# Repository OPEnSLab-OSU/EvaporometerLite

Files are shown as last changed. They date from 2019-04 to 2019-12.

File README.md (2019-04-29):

# EvaporometerLite
This repository contains all the files needed to recreate the Evaporometer LITE.
# How to Setup
Follow assembly guide located in the documentation folder. 

# Directory Layout
Documentation contains assembly procedure, BOM.

CAD contains .stl and .step files of 3D printed components. 

PCB contains PCB design.

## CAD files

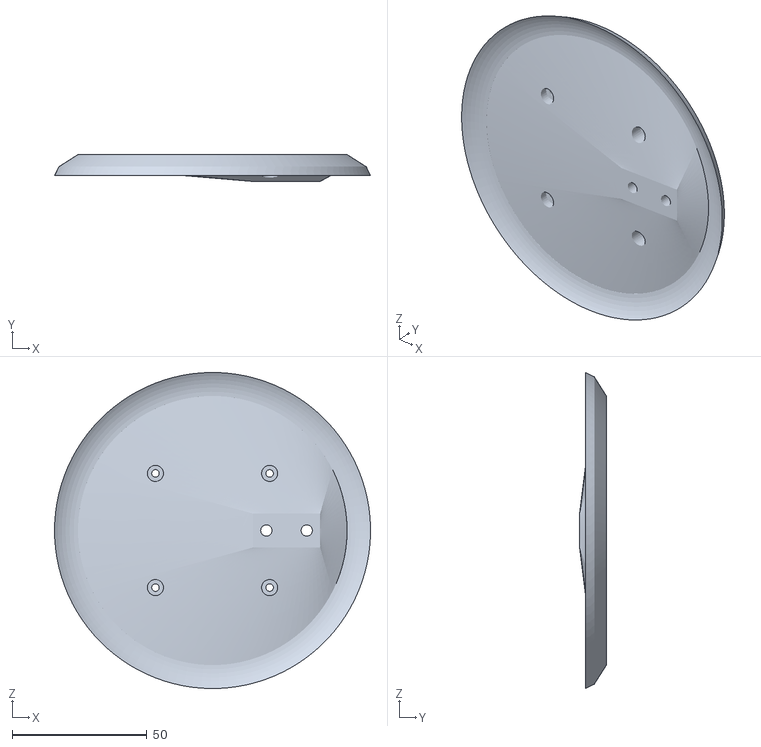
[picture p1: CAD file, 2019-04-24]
CAD /Coupler.stl
117.4 x 10.0 x 117.4

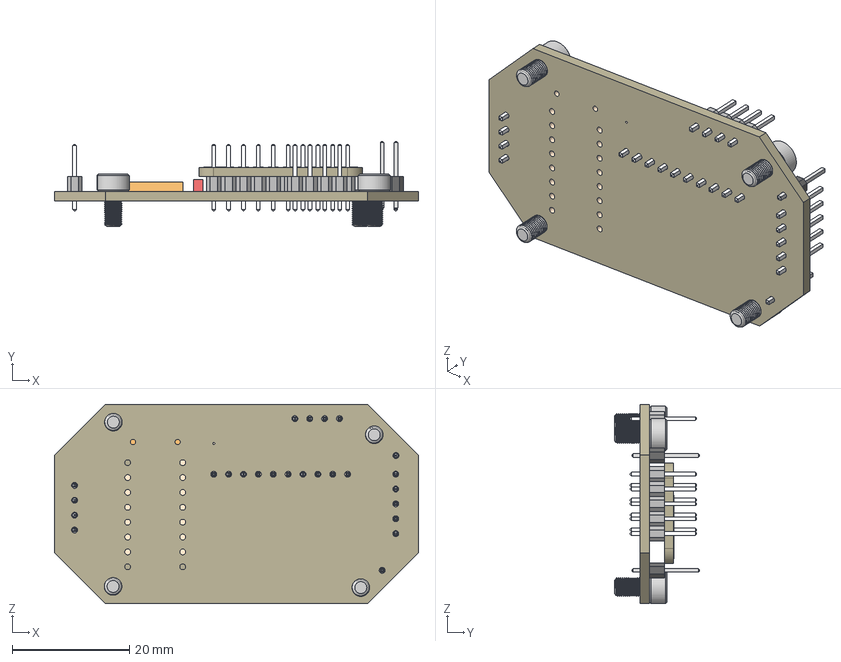
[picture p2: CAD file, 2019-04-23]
PCB/PCB Board.step
62.2 x 14.5 x 34.1 mm
Board
ADS1115IDGST
1µF x 8
MOUNTINGHOLE2.5 x 2
FIDUCIAL"" x 2
ADAFRUIT_TEXT_20MM
ADAFRUIT_2.5MM
Board_1
1X04 x 2
1X05
1X10
1X01 x 2
SJ
90751A110 x 4

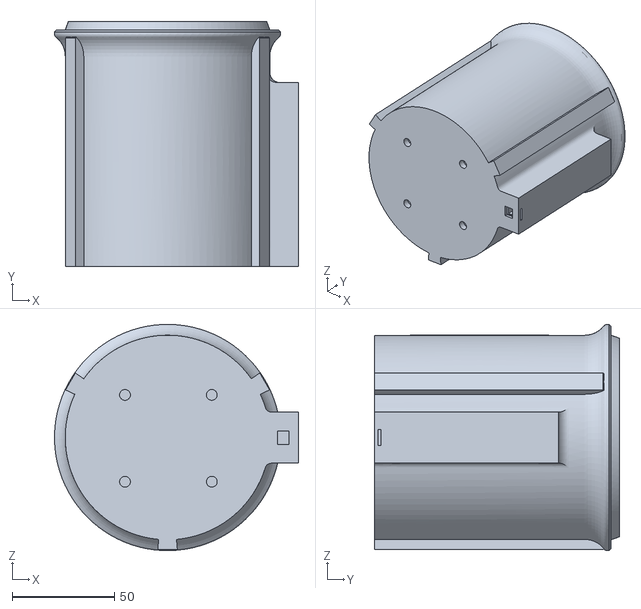
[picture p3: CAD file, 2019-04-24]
CAD /Evaporimter.stl
119.3 x 119.9 x 110.6

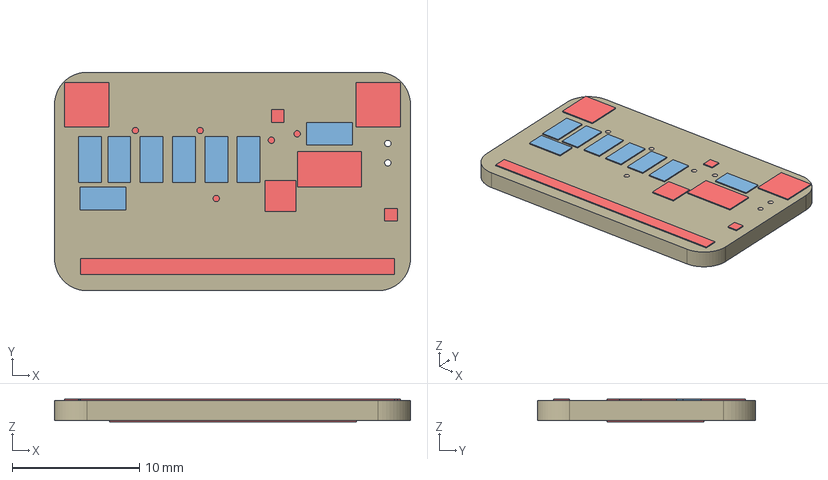
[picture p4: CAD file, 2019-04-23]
PCB/Adafruit ADS1115 16Bit I2C ADC.step
27.9 x 17.1 x 1.77 mm
Board
ADS1115IDGST
1µF x 8
1X10_ROUND70
MOUNTINGHOLE2.5 x 2
FIDUCIAL"" x 2
ADAFRUIT_TEXT_20MM
ADAFRUIT_2.5MM

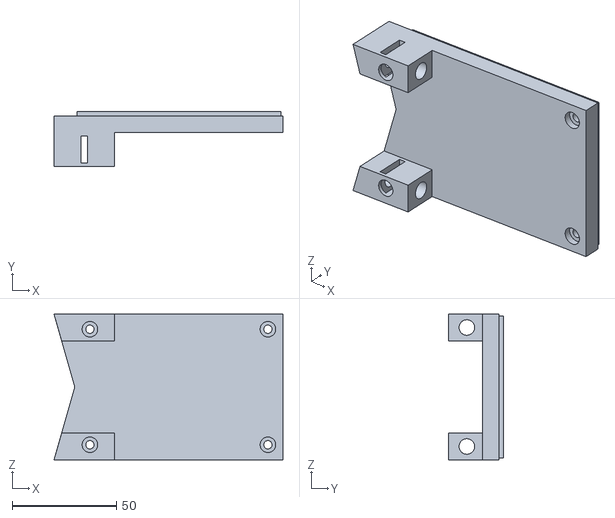
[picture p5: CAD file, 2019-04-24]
CAD /Bottom Enclosure.stl
110.0 x 26.2 x 70.0

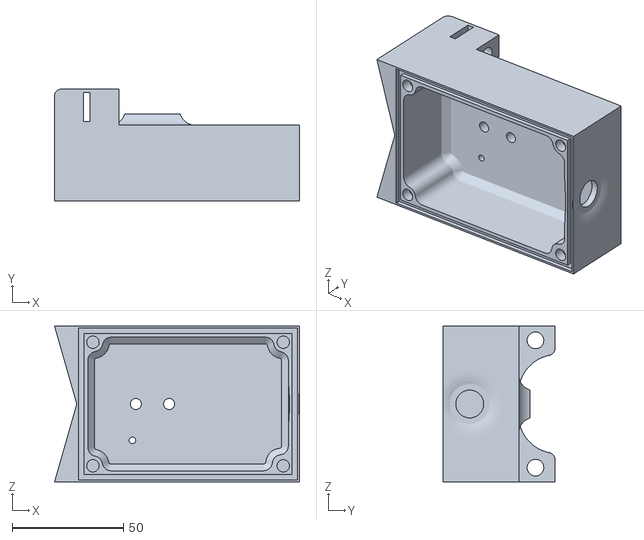
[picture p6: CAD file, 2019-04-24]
CAD /Top Enclosure.stl
110.0 x 50.2 x 70.0

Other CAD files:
CAD /Container Evaporometer LITE.step
CAD /Bottom Enclosure Evaporimeter LITE.step
CAD /Top Enclosure Evaporimeter LITE.step
CAD /Coupler Evaporimeter LITE.step

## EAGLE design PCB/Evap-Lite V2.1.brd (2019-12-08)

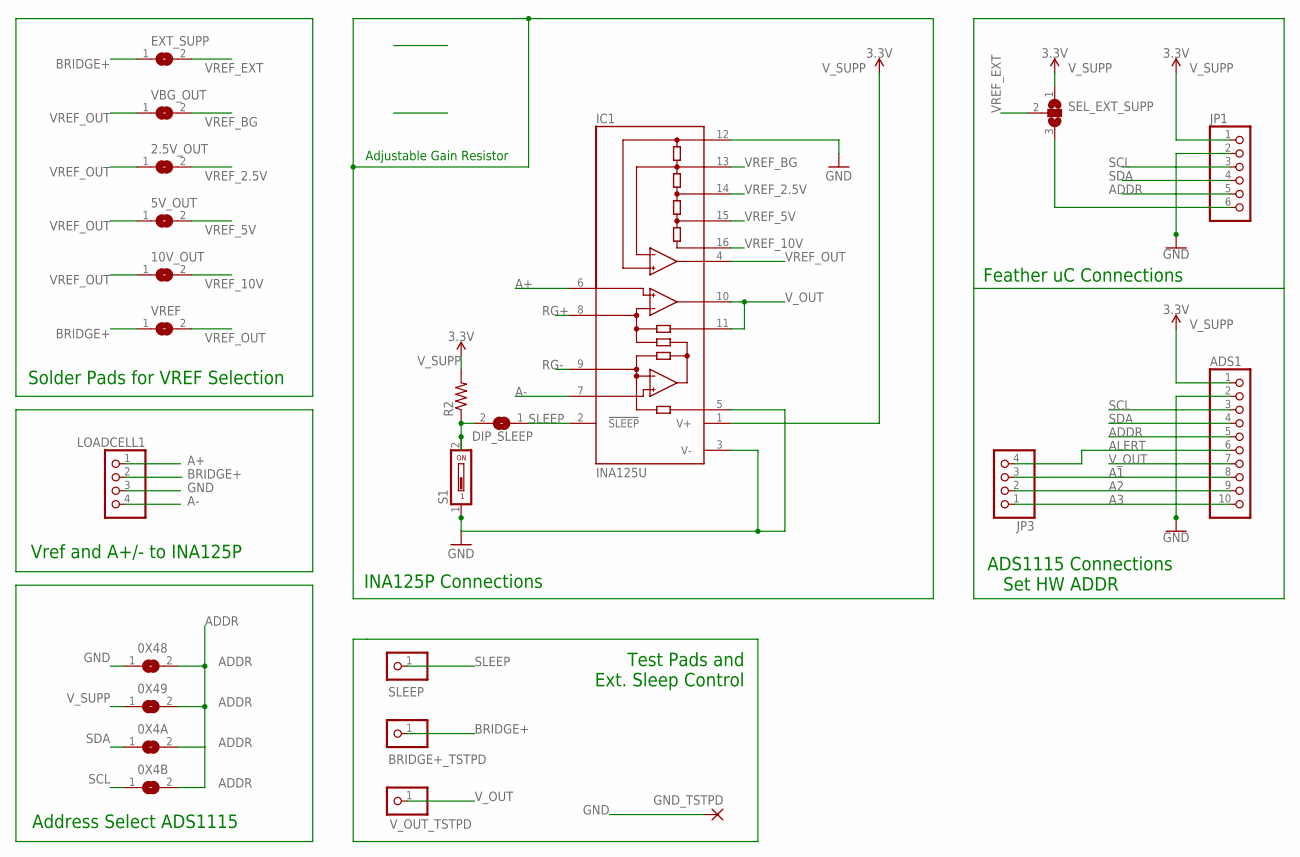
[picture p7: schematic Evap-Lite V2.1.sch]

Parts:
0X4A, 0X4B, 0X48, 0X49, 2.5V_OUT, 5V_OUT, 10V_OUT: SJ
ADS1: PINHD-1X10; 1X10
BRIDGE+_TSTPD: PINHD-1X1; 1X01
DIP_SLEEP: SJ
EXT_SUPP: SJ
GND_TSTPD: WIREPADSMD2,54-5,08; SMD2,54-5,08
IC1: INA125U; SO16-1
JP1: PINHD-1X6; 1X06
JP3: PINHD-1X4; 1X04
LOADCELL1: PINHD-1X4; 1X04
R2: R-US_R1206; R1206
S1: DS01; DS-01
SEL_EXT_SUPP: SJ2WW; SJ_2W
SLEEP: PINHD-1X1; 1X01
VBG_OUT: SJ
VREF: SJ
V_OUT_TSTPD: PINHD-1X1; 1X01

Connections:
A1: ADS1.8, JP3.3
A2: ADS1.9, JP3.2
A3: ADS1.10, JP3.1
A+: IC1.6 (+IN), LOADCELL1.1
A-: IC1.7 (-IN), LOADCELL1.4
ADDR: 0X4A.2, 0X4B.2, 0X48.2, 0X49.2, ADS1.5, JP1.5
ALERT: ADS1.6, JP3.4
BRIDGE+: BRIDGE+_TSTPD.1, EXT_SUPP.1, LOADCELL1.2, VREF.1
GND: 0X48.1, ADS1.2, GND_TSTPD.1, IC1.3 (V-), IC1.5 (REF), IC1.12 (REFCOM), JP1.2, LOADCELL1.3, S1.1
unnamed: JP1.6, SEL_EXT_SUPP.3
unnamed: DIP_SLEEP.2, R2.1, S1.2
RG+: IC1.8 (RG)
RG-: IC1.9 (RG)
SCL: 0X4B.1, ADS1.3, JP1.3
SDA: 0X4A.1, ADS1.4, JP1.4
SLEEP: DIP_SLEEP.1, IC1.2 (!SLEEP), SLEEP.1
VREF_2.5V: 2.5V_OUT.2, IC1.14 (REF2.5)
VREF_5V: 5V_OUT.2, IC1.15 (REF5)
VREF_10V: 10V_OUT.2, IC1.16 (REF10)
VREF_BG: IC1.13 (REFBG), VBG_OUT.2
VREF_EXT: EXT_SUPP.2, SEL_EXT_SUPP.2
VREF_OUT: 2.5V_OUT.1, 5V_OUT.1, 10V_OUT.1, IC1.4 (REFOUT), VBG_OUT.1, VREF.2
V_OUT: ADS1.7, IC1.10 (OUT), IC1.11 (SENSE), V_OUT_TSTPD.1
V_SUPP: 0X49.1, ADS1.1, IC1.1 (V+), JP1.1, R2.2, SEL_EXT_SUPP.1

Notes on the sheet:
Vref and A+/- to INA125P
Solder Pads for VREF Selection
Feather uC Connections
Address Select ADS1115
ADS1115 Connections Set HW ADDR
Adjustable Gain Resistor
INA125P Connections
Test Pads and Ext. Sleep Control

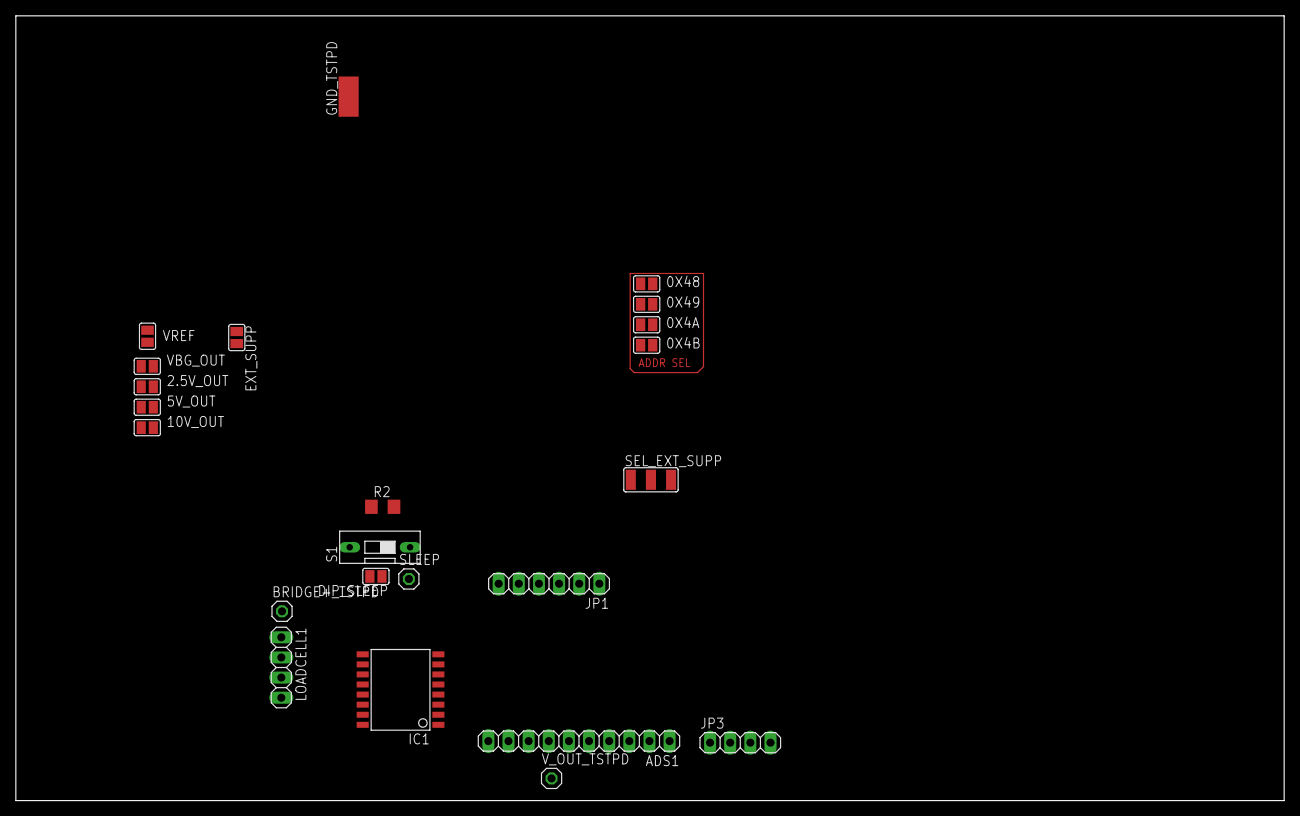
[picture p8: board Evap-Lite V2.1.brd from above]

Board: 2 copper layers, 160.0 x 99.0 mm, 23 parts (0 on the bottom side), 22 nets.

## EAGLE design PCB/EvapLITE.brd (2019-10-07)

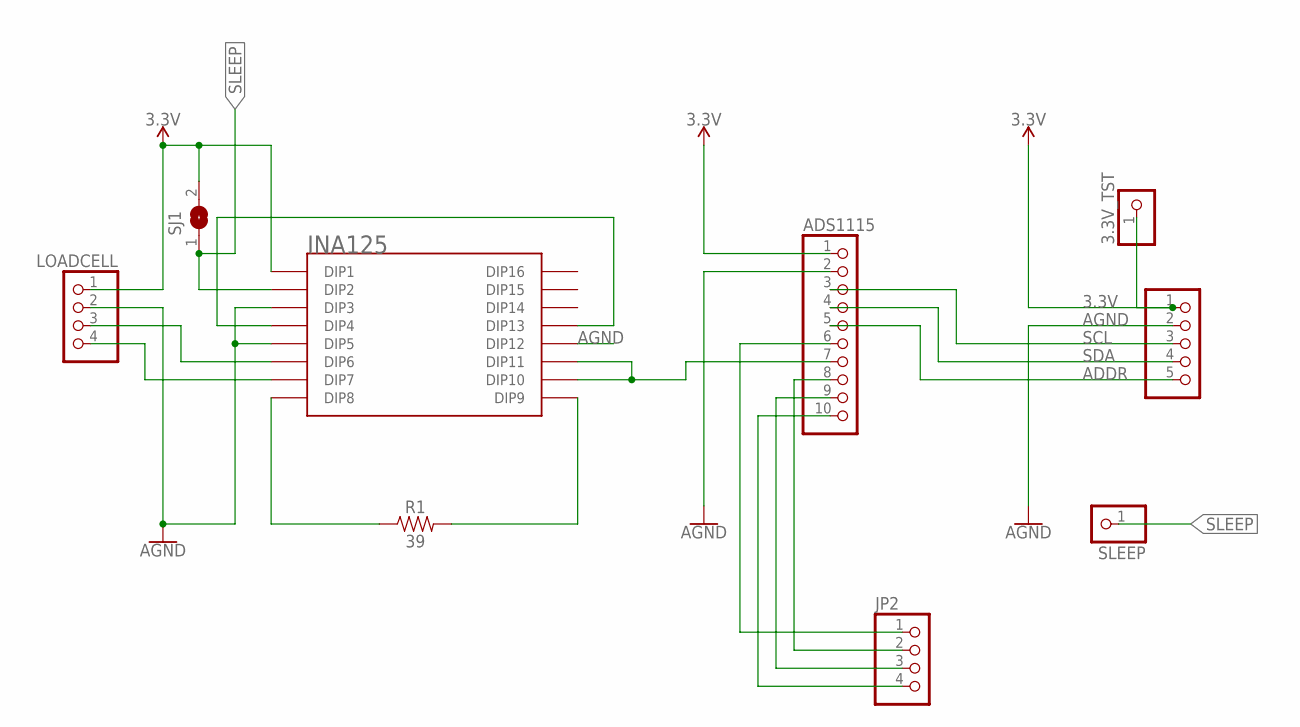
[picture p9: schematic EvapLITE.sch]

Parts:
3.3V_TST: PINHD-1X1; 1X01
ADS1115: PINHD-1X10; 1X10
I2C: PINHD-1X5; 1X05
INA125: 16-PIN_DIP
JP2: PINHD-1X4; 1X04
LOADCELL: PINHD-1X4; 1X04
R1: 39; AXIAL-0.3
SJ1: SJ
SLEEP: PINHD-1X1; 1X01

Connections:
3.3V: 3.3V_TST.1, ADS1115.1, I2C.1, INA125.DIP1, LOADCELL.1, SJ1.2
ADDR: ADS1115.5, I2C.5
AGND: ADS1115.2, I2C.2, INA125.DIP3, INA125.DIP5, INA125.DIP12, LOADCELL.2
unnamed: INA125.DIP4, INA125.DIP13
unnamed: INA125.DIP6, LOADCELL.3
unnamed: INA125.DIP7, LOADCELL.4
unnamed: INA125.DIP8, R1.P$1 (1)
unnamed: INA125.DIP9, R1.P$2 (2)
unnamed: ADS1115.7, INA125.DIP10, INA125.DIP11
unnamed: ADS1115.8, JP2.2
unnamed: ADS1115.9, JP2.3
unnamed: ADS1115.10, JP2.4
unnamed: ADS1115.6, JP2.1
SCL: ADS1115.3, I2C.3
SDA: ADS1115.4, I2C.4
SLEEP: INA125.DIP2, SJ1.1, SLEEP.1

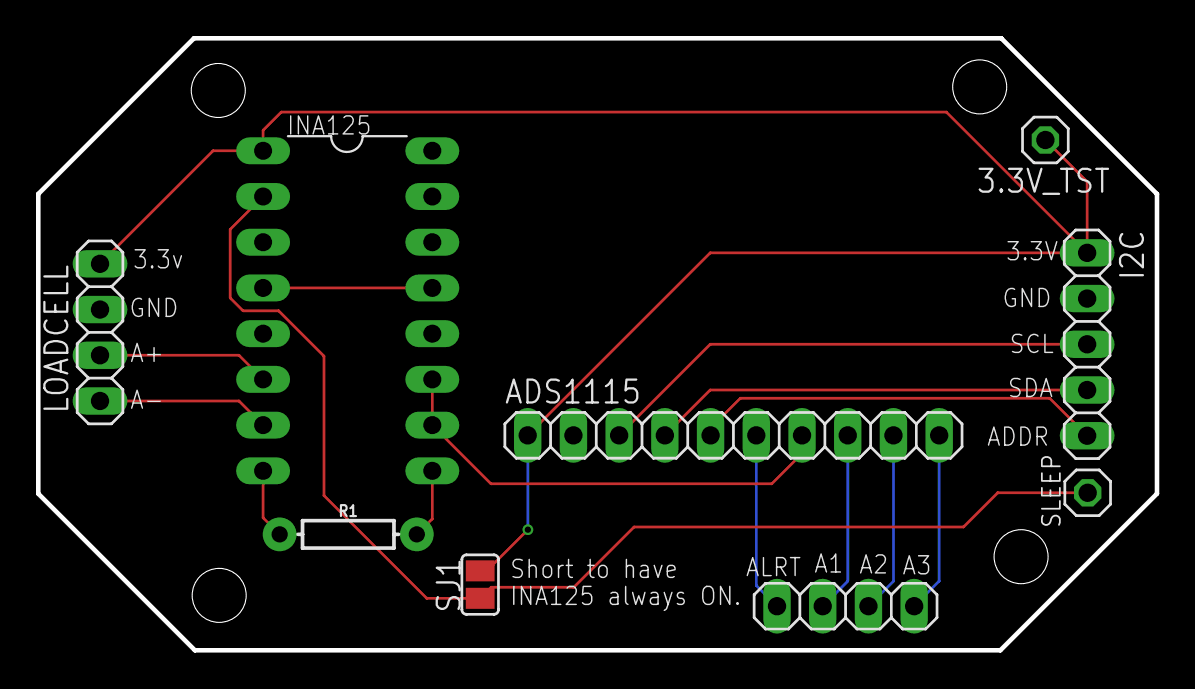
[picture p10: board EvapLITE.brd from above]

Board: 2 copper layers, 62.2 x 34.0 mm, 9 parts (0 on the bottom side), 16 nets.

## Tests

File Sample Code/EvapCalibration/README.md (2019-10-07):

---Process for Calibrating Load Cell---
1. Create spreadsheet to record measured digital value vs added weight
2. Run code and add weights at even intervals(weight maxes out at 850 grams
3. Record each measured digital value vs added weight into spreadsheet
4. Use built in linear regression tools to determine a slope and intercept
5. Input slope and intercept into code and change CALIBRATE to 0 and CHECK to 1 to
   run the code in the check mode
6. Verify the calculated linear equation is correct by re-adding weights and checking
   that the code calculates an accurate value

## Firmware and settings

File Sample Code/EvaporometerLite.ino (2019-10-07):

/******************************************************
 * Evaporometer Lite
 * Written By Elijah Shumway
 * 05/20/2019
 ******************************************************/
#include <Wire.h>
#include <SD.h>
#include <SPI.h>
#include <Adafruit_ADS1015.h>
#include "RTClib.h"
#include "Adafruit_SHT31.h"


/*---------------Define features of the board on or off--------------------*/
#define DEBUG 0 //set to 1 to get more Serial out statements
#define sd 1 //write 1 if using sd card dataloggger
#define SHT 0 //write 1 if using SHT temp/humidity sensor
/*-------------------------------------------------------------------------*/

/*-------------------------variable definitions-----------------------------*/
#define mux1  0x70 //defines the multiplexer address
#define num_ports 8 //defines how many ports are on the multiplexer
#define num_sensors 3 //defines how many sensors are in use
#define num_mux 1 //defines how many multiplexers are in use
#define card_select 10 //for SD card and datalogger
#define slope 19.775 //calculated slope for getting weight values from ADSD1115
#define delay_time 600000 //set time between measurements in milliseconds


/*------------------------Class Declarations for Sensors-----------------------------*/
DateTime now; //sets time
File data; //declares variable for datalogger
RTC_PCF8523 rtc; //initializes real time clock
Adafruit_SHT31 sht31 = Adafruit_SHT31();
/*-----------------------------------------------------------------------------------*/

/*------------------------Evaporometer Struct Declaration----------------------------*/
struct state_ads1115{
  Adafruit_ADS1115 ads; //initializes ads1115
  bool is_setup = 0; //tells whether the struct has been setup
  float weight; //float for storing current weigt value
  float zero; //float for storing individual zero counts
};
/*-----------------------------------------------------------------------------------*/


/*------------------------------Array Declarations-----------------------------------*/
byte addresses[num_mux] = {mux1}; //array for storing mux addresses

state_ads1115 sensors[num_sensors]; //struct array for ADS
/*------------------------------------------------------------------------------------*/

/*****************************************************************
 * tcaselect
 * Selects port on TCA multiplexer for communication
 * Inputs: TCA multiplexer address, int 0<i<7 for port selection
 * Outputs: Selects port on multiplexer to communicate with
 ****************************************************************/

void tcaselect(byte addrs, uint8_t i) {
  if (i > 7 or i < 0){
    Serial.println("Mux Address Out Of Bounds"); //error handling
    return;
  }
  if (addrs > 0x77 or addrs < 0x70){
    Serial.println("Address Out Of Bounds"); //error handling
    return;
  }
  Wire.beginTransmission(addrs); //communicates with the ports on the mux board
  Wire.write(1 << i); //initializes the port for communication
  Wire.endTransmission();  //turns on the port
}

/*************************************************************************
 * set_weight
 * Reads loadcell data from ads1115 and stores into state_ads1115 struct
 * Inputs: ads1115 struct from array
 * Outputs: weight value into state_ads1115 struct
 ************************************************************************/

void set_weight(state_ads1115& state_ads){
  float w = 0;
  float w_ave = 0;
  for(int i = 0; i < 10; i++){
    w = state_ads.ads.readADC_SingleEnded(0); //reads onboard ADS1115
    w = w-state_ads.zero; //subtracts tared zero value from read weight
    w = w/slope; //divides by calculated slope
    w_ave+=w;
  }
  w_ave = w_ave/10;
  state_ads.weight = w_ave; //sets struct weight to calculated weight
}
/***********************************************************
 * setup_ads1115
 * sets up and tares the evaporometer load cell
 * Inputs: ads1115 struct from array
 * Outputs: initialized ads1115
 *********************************************************/
void setup_ads1115(state_ads1115& state_ads){
  state_ads.ads.begin(); //initializes onboard ADS1115
  state_ads.ads.setGain(GAIN_ONE); 
  state_ads.zero=tare(state_ads.ads); //runs the tare function for the individual state_ads
  #if DEBUG
   Serial.print("Zero in setup: ");
   Serial.println(state_ads.zero);
  #endif
  state_ads.is_setup=1;
}
/*****************************************************************************************
 * tare
 * takes an average of 500 readings to calculate an initial average to tare loadcell
 * Inputs: Adafruit_ADS1115 from state_ads1115 struct
 * Outputs: Tares loadcell and returns the zero value for storing in state_ads1115 struct
 ****************************************************************************************/
float tare(Adafruit_ADS1115 ads){
   float z = 0; //float to store running total for averaging
  int16_t s = 0; //int to store current data value
  for(int i=0; i<500; i++){
      s=ads.readADC_SingleEnded(0); //read current data value from ADS1115 
      z=z+s; //add current data value to running total for averaging
      #if DEBUG
        Serial.print("Value: ");    
        Serial.println(s);   // Serial out statements for testing/debug purposes 
        Serial.println(z);
      #endif
      delay(1); 
  }
  z=z/500; //divide z by number of iterations to get average for zeroing out
 // Serial.print("Z= ");    //debug print statements
  //Serial.println(z);
  
  return z; //returns the calculated zero value
}

int count = 0; //variable for selecting from ads array

void setup() {
  pinMode(13,OUTPUT); //initialize pin for displaying errors
  
  #if SHT
  //Serial.println("SHT31 test");
  if (! sht31.begin(0x44)) {   //Initializes temperature/humidity sensor
    Serial.println("Couldn't find SHT31"); 
    digitalWrite(13,HIGH); //turns LED on if sensor cannot be initialized
    while (1) delay(1);
  }
  #endif
  
  Serial.begin(9600);
  #if sd
    while(!SD.begin(card_select)){
      Serial.println("Missing SD Card..."); //error handling for missing/broken SD card
      delay(100);
    }
    #if DEBUG
      Serial.println("SD initialized");
    #endif
            
  #endif
  
   Wire.begin(); //initializes I2C communication
 
  
  for(int i=0; i<num_mux; i++){
    for(int j=0; j<num_sensors; j++){
      tcaselect(addresses[i],j); //selects the multiplexer and port on multiplexer to gather data from
      setup_ads1115(sensors[count]); //sets up the sensor at selected port
      #if DEBUG
        Serial.print("Mux ");
        Serial.print(i);
        Serial.print(" port "); //
        Serial.print(j);
        Serial.println(" set up");
      #endif
      count++; //moves to the next sensor in the array
    }
  }
   Serial.println("Sensors Initialized");
}

void loop() {
  #if SHT
    float temp = sht31.readTemperature(); //reads SHT for temperature and humdity data
    float hmdty = sht31.readHumidity();
    #if DEBUG
      Serial.println(temp);
      Serial.println(hmdty);
    #endif
  #endif
  
  count = 0; 
  for(int i=0; i<num_mux; i++){
    for(int j=0; j<num_sensors; j++){
      tcaselect(addresses[i],j); //selects the multiplexer and port on multiplexer to gather data from
      set_weight(sensors[count]); //gathers weight data from sensor and sets weight value within struct

       count++;
    }
  }
    count = 0;
    //loop for displaying gathered data to the Serial monitor and the SD card
  for(int i=0; i<num_mux; i++){
    for(int j=0; j<num_sensors; j++){
     Serial.print("Weight ");
     Serial.print(count);
     Serial.print(": ");
     Serial.println(sensors[count].weight);
     count++;
     
    }
  }
  now=rtc.now();
  #if DEBUG
    Serial.println("RTC Set");
  #endif
  
  #if sd
    data = SD.open("evapdata.txt",FILE_WRITE); //datalogging
    digitalWrite(13,LOW); 
    if(data){
      count = 0;
        //prints time data onto sd card
        
        data.print(now.month());
        data.print('-');
        data.print(now.day());
        data.print('-');
        data.print(now.year());
        data.print(" ");
        data.print(now.hour(), DEC);
        data.print(':');
        data.print(now.minute(), DEC);
        data.print(':');
        data.print(now.second(), DEC);
       // data.print(",");
    for(int i=0; i<num_mux; i++){
      for(int j=0; j<num_sensors; j++){
        tcaselect(addresses[i],j);
        data.print(",");
        data.print(sensors[count].weight);
        count++;
      }
    }
        #if SHT //prints temperature and humdity data to SD card
          data.print(",");
          data.print(temp);
          data.print(",");
          data.print(hmdty);
        #endif
    data.println();
    
    #if DEBUG
      Serial.println("data in sd buffer");
    #endif
    
    data.close(); //writes data to sd card
    
    #if DEBUG
      Serial.println("data printed to SD card");
    #endif
    
    }
    else{
      Serial.println("Error opening file");
      digitalWrite(13,HIGH);
    }

  #endif
  
 delay(delay_time); //delays between readings
}

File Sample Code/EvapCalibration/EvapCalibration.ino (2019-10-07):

#include <Wire.h>
#include <Adafruit_ADS1015.h>

#define CALIBRATE 1 //define as 1 to run in calibration mode
#define CHECK 0     //define as 1 to run in check mode to verify calibration

#define slope 0     //set to calculated slope from linear regression
#define zero 0      //set to calculated zero from linear regression

Adafruit_ADS1115 ads1115(0x48);

int samples = 20; //set how many samples are taken for averaging
void setup() {
  Serial.begin(9600);
  ads1115.begin(); //initialize ADC on Evap board
  ads1115.setGain(GAIN_ONE); //sets built in ADC Gain
}

void loop() {
  #ifdef CALIBRATE
    int val = 0; //reset val to 0 after each average
    for(int i=0; i<samples; i++){
       val+=ads1115.readADC_SingleEnded(0); //reads value from ADC
    }
    val = val/samples;  //averages measured value 
    Serial.println(val); //prints value to terminal
    delay(250);
  #endif

  #ifdef CHECK
    int digital_weight = 0;
    int check_val = 0;
    for(int i=0; i<samples; i++) 
      check_val+=ads1115.readADC_SingleEnded(0); //reads value from ADC
    
    check_val = check_val/samples; //averages measured value
    
    digital_weight*=slope;
    digital_weight-=zero;
    
    Serial.println(digital_weight);
    delay(250);
  #endif
}

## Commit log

2019-04-23 Coupler CAD file
    [Coupler Evaporimeter LITE.step]
2019-04-23 Uploaded more CAD files
    [Bottom Enclosure Evaporimeter LITE.step, Container Evaporometer LITE.step, Top Enclosure Evaporimeter LITE.step]
2019-04-23 PCB board/Ads 1115
    [Adafruit ADS1115 16Bit I2C ADC.step, PCB Board.step]
2019-04-24 Uploaded stl CAD files
    [Bottom Enclosure.stl, Coupler.stl, Evaporimter.stl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]
2019-06-10 Added Temperature dependency test
2019-07-29 Voltage measurements
2019-07-29 voltage measurement
2019-10-07 added schematic and board files for EvapLite PCB
    [EvapLITE.brd, EvapLITE.sch]

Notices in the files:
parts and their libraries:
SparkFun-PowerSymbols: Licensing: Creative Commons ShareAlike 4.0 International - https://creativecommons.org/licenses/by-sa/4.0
